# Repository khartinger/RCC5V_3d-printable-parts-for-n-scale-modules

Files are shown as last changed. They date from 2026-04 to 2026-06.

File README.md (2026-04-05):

<table><tr><td></td><td>
Last modified: 2026-04-02 <br>   
<h1>3D Printable Parts for N Scale Modules</h1>
<a href="LIESMICH.md">==> Deutsche Version</a>&nbsp; &nbsp; &nbsp; 
</td></tr></table>   

<a href="LIESMICH.md"><b> Sorry! This page is currently only available in German.</b></a>   

[To the top of the page](#up)

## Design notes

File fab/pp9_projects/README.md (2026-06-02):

<table><tr><td></td><td>
Last modified: 2026-05-27 <br>   
<h1>RCC5V: Little 3D Projects</h1><h3>3D Printable Parts for N Scale Modules</h3>
<a href="LIESMICH.md">==> Deutsche Version</a>&nbsp; &nbsp; &nbsp; 
</td></tr></table>   

<a href="LIESMICH.md"><b> Sorry! This page is currently only available in German.</b></a>   

[To the top of the page](#up)

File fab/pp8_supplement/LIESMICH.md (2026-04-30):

<table><tr><td></td><td>
Letzte &Auml;nderung: 30.4.2026 <br>   
<h1>RCC5V Ergänzungsteile</h1><h3>3D-Druck-Teile für N-Spur-Module</h3>
<a href="#TableOfContents">==> Inhaltsverzeichnis</a>&nbsp; &nbsp; &nbsp;  &nbsp; 
<a href="README.md">==> English version</a>
</td></tr></table>   

# 1. Worum geht es?
Dieses Verzeichnis enthält **Ergänzungsteile**, mit deren Hilfe der Bahnkörper begradigt wird. Das Bild zeigt Straßenteile für einen Bahnübergang.   
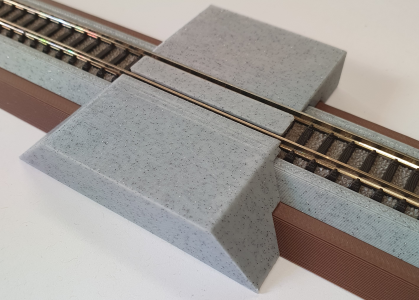
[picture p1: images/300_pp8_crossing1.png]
Bahnuebergang
   

Die Höhe der Teile orientiert sich an folgender Ebenen-Einteilung:   
* E0 . . . . . Oberkante der Basisplatte (= 6 cm &uuml;ber einer Tischplatte). Auf dieser Ebene werden der Bahndamm und, darauf aufbauend, das Schotterbett aufgesetzt.   
* E5 . . . . . Oberkante des Bahndamms. Auf dieser Ebene setzt das Schotterbett auf.   
* E8 . . . . . Auf dieser Ebene liegt das Modellgleis. Hier werden auch Modell-Bahnsteige und Bahnh&ouml;fe platziert. In der Realit&auml;t gibt es diese Ebene eigentlich nicht, da sie mitten in der H&ouml;he des Schotterbettes liegt.   
* E10 . . . . . Oberkante des Schotterbettes bzw. Unterkante des Gleises.   
* E12 . . . . . Oberkante des Gleises. Stra&szlig;en f&uuml;r Bahn&uuml;bersetzungen sollten dieses Niveau haben, wobei Bahn&uuml;bergang-Baus&auml;tze oft eine Art "Rampe" bzw. Auffahrt haben, weil die Baus&auml;tze &uuml;blicherweise auf Ebene E8 platziert werden.   

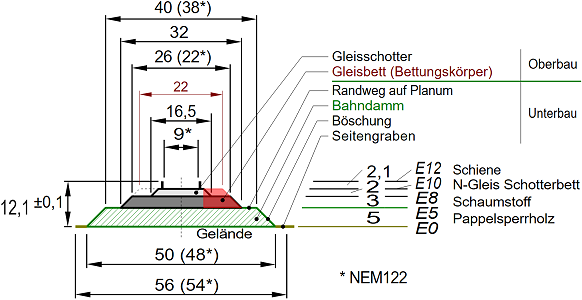
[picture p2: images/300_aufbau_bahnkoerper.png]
Aufbau Bahnk&ouml;rper
   

## Inhaltsverzeichnis
1. [Worum geht es?](#x10)   
2. [Bahnübergang](#x20)   

# 2. Bahnübergang (E12)
Für die Straße bei Bahnübergängen gibt es die Breiten 44 mm und 50 mm mit senkrechter Seitenwand bzw. 68 mm und 74 mm mit schräger Seitenwand (45°). (Siehe Bild oben)  

**Freecad-Dateien**:   
[./fcstd/suppl_straight_E12_44mm_260430.FCStd](https://github.com/khartinger/RCC5V_3d-printable-parts-for-n-scale-modules/tree/main/fab/pp8_supplement/fcstd/suppl_straight_E12_44mm_260430.FCStd)   
[./fcstd/suppl_straight_E12_50mm_260430.FCStd](https://github.com/khartinger/RCC5V_3d-printable-parts-for-n-scale-modules/tree/main/fab/pp8_supplement/fcstd/suppl_straight_E12_50mm_260430.FCStd)   
[./fcstd/suppl_straight_E12_68mm_crossing_260430.FCStd](https://github.com/khartinger/RCC5V_3d-printable-parts-for-n-scale-modules/tree/main/fab/pp8_supplement/fcstd/suppl_straight_E12_68mm_crossing_260430.FCStd)   
[./fcstd/suppl_straight_E12_74mm_crossing_260430.FCStd](https://github.com/khartinger/RCC5V_3d-printable-parts-for-n-scale-modules/tree/main/fab/pp8_supplement/fcstd/suppl_straight_E12_74mm_crossing_260430.FCStd)   

**Slicer-Dateien**:   
[./3mf/suppl_straight_E12_44mm_260430.3mf](https://github.com/khartinger/RCC5V_3d-printable-parts-for-n-scale-modules/tree/main/fab/pp8_supplement/3mf/suppl_straight_E12_44mm_260430.3mf)   
[./3mf/suppl_straight_E12_50mm_260430.3mf](https://github.com/khartinger/RCC5V_3d-printable-parts-for-n-scale-modules/tree/main/fab/pp8_supplement/3mf/suppl_straight_E12_50mm_260430.3mf)   
[./3mf/suppl_straight_E12_68mm_crossing_260430.3mf](https://github.com/khartinger/RCC5V_3d-printable-parts-for-n-scale-modules/tree/main/fab/pp8_supplement/3mf/suppl_straight_E12_68mm_crossing_260430.3mf)   
[./3mf/suppl_straight_E12_74mm_crossing_260430.3mf](https://github.com/khartinger/RCC5V_3d-printable-parts-for-n-scale-modules/tree/main/fab/pp8_supplement/3mf/suppl_straight_E12_74mm_crossing_260430.3mf)   

Zwischen die Gleise wird ein Übergangsbelag gelegt:   
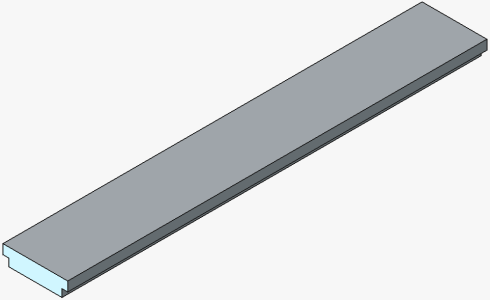
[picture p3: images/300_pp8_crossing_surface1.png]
Bahnuebergang_Uebergangsbelag
   

**Freecad-Datei(en)**:   
[./fcstd/suppl_straight_44mm_crossing_surface_260430.FCStd](https://github.com/khartinger/RCC5V_3d-printable-parts-for-n-scale-modules/tree/main/fab/pp8_supplement/fcstd/suppl_straight_44mm_crossing_surface_260430.FCStd)   
**Slicer-Datei(en)**:   
[./3mf/suppl_straight_44mm_crossing_surface_260430.3mf](https://github.com/khartinger/RCC5V_3d-printable-parts-for-n-scale-modules/tree/main/fab/pp8_supplement/3mf/suppl_straight_44mm_crossing_surface_260430.3mf)   

# 3. Gelände-Begradigung für Gebäude (E8)

# 4. Gelände-Begradigung bei mehreren Gleisen (E10)

[Zum Seitenanfang](#up)

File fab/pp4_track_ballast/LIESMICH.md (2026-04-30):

<table><tr><td></td><td>
Letzte &Auml;nderung: 17.4.2026 <br>   
<h1>Schotterbett (Track Ballast)</h1><h3>3D-Druck-Teile für N-Spur-Module</h3>
<a href="#TableOfContents">==> Inhaltsverzeichnis</a>&nbsp; &nbsp; &nbsp;  &nbsp; 
<a href="README.md">==> English version</a>
</td></tr></table>   

# 1. Worum geht es?
Dieses Verzeichnis enthält **Schotterbett-Dateien** für N-Piccolo-Gleise mit Schotterbett (Fa. Fleischmann) im N‑Spur‑Maßstab (1:160). In diese 3D-Drucke werden die Fleischmann-Gleise eingelegt, damit ein breiteres Schotterbett entsteht.   

_Beispiel_: Schotterbett für gerades Gleis 9103   
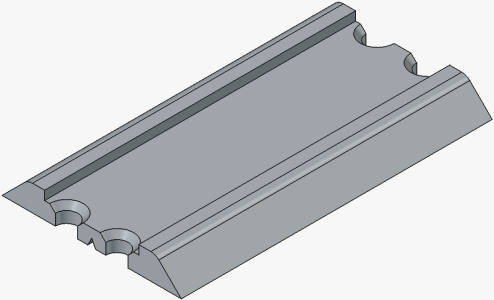
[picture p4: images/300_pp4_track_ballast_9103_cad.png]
Schotterbett Gerade 9103
   

Für alle Modelle gilt:   
* An den Verbindungskanten befinden sich zwei halbe Bohrungen. So können an jeder Stoßstelle Kabel für die Gleisstromversorgung durchgeführt werden. Da sich die Bohrungen unter dem Gleisbett befinden, sind sie von außen nicht sichtbar.   
* In der Mitte der Unterseite der Modelle ist eine Nut. Der Bahndamm hat die dazu passende Erhebung. Damit kann die Lage von 3D-Schotterbett und Bahndamm leicht angepasst werden.   
* Die Längsoberkanten sind abgerundet.   

## Inhaltsverzeichnis
1. [Worum geht es?](#x10)   
2. [Schotterbett für gerade Gleise](#x20)   
3. [Schotterbett für gebogene Gleise](#x30)   
4. [Verkürztes Schotterbett](#x40)   
5. [Schotterbett für Weichen](#x50)   

# 2. Schotterbett für gerade Gleise
Für gerade Gleise gibt es folgende Schotterbetten:   
* 9100 (222 mm)   
* 9101 (111 mm)   
* 9102 (57,5 mm)   
* 9103 (55,5 mm)   
* 9104 (27,75 mm)   
* 9110 (Ausgleichsgleis, 83 mm bis 111 mm)   
* 9116 (Prellbock, 57,5 mm)   

Weitere Besonderheiten sind:   
* `Gerade_Schotter_Abschluss_260327` ... Abschlussstück bei Gleisenden (Prellbock)   
* `Gerade_Schotter_Iso_0.5mm_260327` ... Gerades Gleisstück mit 0,5 mm Länge, wenn Verlängerungen durch Gleisisolierschuhe ausgeglichen werden sollen.   
* `Gerade_Schotter_9101_adWeiche_260327.FCStd` ... Gerades Gleis 9101, bei dem ein Teil des Randschotters entfernt ist. Damit passt es zu Weichen.   
* `Gerade_Schotter_9104_adWeiche_260327.FCStd` ... Wie `Gerade_Schotter_9101_adWeiche_260327.FCStd`, aber für Gleis 9104.   

# 3. Schotterbett für gebogene Gleise
Für gebogene Gleise gibt es folgende Schotterbetten:   
* `Bogen_Schotter_R2_7.5_9128_260327.FCStd` ... Radius R2 (225,6 mm), Winkel 7,5°   
* `Bogen_Schotter_R2_15_9127_260327.FCStd` ... Radius R2 (225,6 mm), Winkel 15°   
* `Bogen_Schotter_R2_45_9125_260327.FCStd` ... Radius R2 (225,6 mm), Winkel 55°   
* `Bogen_Schotter_R3_15_9131_260327.FCStd` ... Radius R3 (396,4 mm), Winkel 15°   
* `Bogen_Schotter_R4_15_9136_260327.FCStd` ... Radius R4 (430 mm), Winkel 15°   

Weitere Besonderheiten sind:   
* `Bogen_Schotter_R3_9.978_9131_260327.FCStd` ... Radius R3 (396,4 mm), Winkel 9,978°   

# 4. Verkürztes Schotterbett
Gleise am Rand des Moduls reichen bis zur Modulkante. Das 3D-Schotterbett endet bereits einen Zentimeter vorher, da der Modul-Seitenteil den Aufbau des Bahnkörpers enthält.   
Weiters gibt es an der Kante zum Seitenteil keine halben Bohrungen.   

Die verkürzten Schotterbetten enthalten im Namen die Bezeichung "-10mm".   
_Beispiele_:   
`Gerade_Schotter_9101_-10mm_260403.FCStd`   
`Gerade_Schotter_9102_-10mm_260403.FCStd`   
`Gerade_Schotter_9103_-10mm_260403.FCStd`   
`Gerade_Schotter_9104_-10mm_260403.FCStd`   

# 5. Schotterbett für Weichen

[Zum Seitenanfang](#up)

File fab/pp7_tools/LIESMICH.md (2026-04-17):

<table><tr><td></td><td>
Letzte &Auml;nderung: 15.4.2026 <br>   
<h1>Werkzeuge und Hilfsmittel</h1><h3>3D-Druck-Teile für N-Spur-Module</h3>
<a href="#TableOfContents">==> Inhaltsverzeichnis</a>&nbsp; &nbsp; &nbsp;  &nbsp; 
<a href="README.md">==> English version</a>
</td></tr></table>   

# 1. Worum geht es?
Dieses Verzeichnis enthält **Werkzeuge** und **Hilfsmittel** für den Bau von Modulrahmen, Gleisunterbau und Zubehörteilen im N‑Spur‑Maßstab (1:160).   
Weitere Hilfsmittel finden sich auch unter [https://github.com/khartinger/RCC5V/blob/main/fab/3d/LIESMICH.md](https://github.com/khartinger/RCC5V/blob/main/fab/3d/LIESMICH.md).   

## Inhaltsverzeichnis
1. [Worum geht es?](#x10)   
2. [Halterung zur Montage eines Unterflur-Weichenantriebs](#x20)   
3. [Schablonen für das Loch bei Unterflurweichen](#x30)   
4. [Gleis-Schnittlehre](#x40)   

# 2. Halterung zur Montage eines Unterflur-Weichenantriebs

Unterflur-Weichenantriebe können mit der Zeit defekt werden und müssen ersetzt werden.   
Da die Weichenantriebs-Öffnungen in der Grundplatte klein sind, ist der Ein- und Ausbau oft schwierig.   

Zum Einbau hilft der folgende **Weichenantriebswechsler**:   

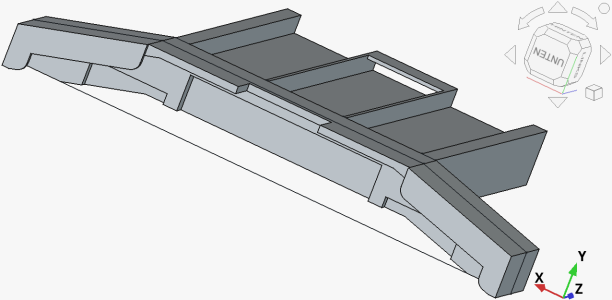
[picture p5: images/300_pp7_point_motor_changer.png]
Weichenantriebswechsler


Der Weichenantrieb wird vorne in die Halterung gesteckt.  
Danach kann er von unten einfach in die Weiche eingesetzt werden.   

**Freecad-Datei**: 
[./fcstd/Weichenantriebswechsler_260226.FCStd](https://github.com/khartinger/RCC5V_3d-printable-parts-for-n-scale-modules/tree/main/fab/pp7_tools/fcstd/Weichenantriebswechsler_260226.FCStd)   
**Slicer-Datei**: 
[./3mf/Weichenantriebswechsler_260226.3mf](https://github.com/khartinger/RCC5V_3d-printable-parts-for-n-scale-modules/tree/main/fab/pp7_tools/3mf/Weichenantriebswechsler_260226.3mf)   

[Zum Seitenanfang](#up)   

# 3. Schablonen für das Loch bei Unterflurweichen
Für die Montage von Unterflur-Weichen gibt es je nach Weichenart unterschiedliche Öffnungen (Löcher). Damit man sie nicht jedes Mal anzeichnen muss, ist eine Schablone hilfreich.   

### Zweiweg-Weichen
Das Bild zeigt die sinnvoll kleinste Ausnehmung für einen Zweiweg-Weichenantrieb.   
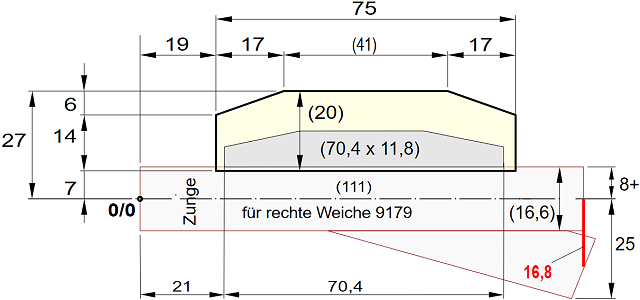
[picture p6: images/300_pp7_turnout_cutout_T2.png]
Maße_Loch_Zweiwegweiche
   

Die Eckpunkte der Öffnung sind (19/7), (94/7), (94/21), (77/27), (36/27) und (19/21).   

Schablone:   
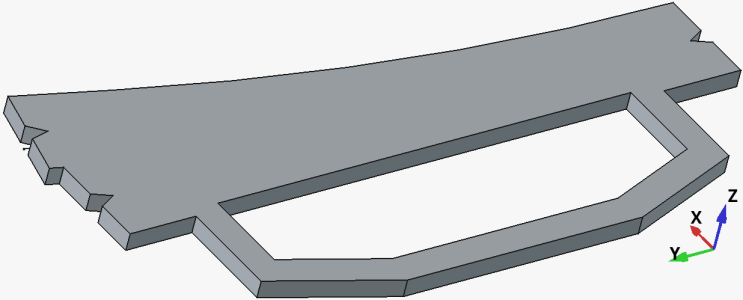
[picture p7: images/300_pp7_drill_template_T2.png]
Schablone_Loch_Zweiwegweiche
   

**Anmerkung**: Falls Platz vorhanden ist, darf die Ausnehmung auch größer sein...   

**Freecad-Datei**: 
[./fcstd/drill_template_T2_260413.FCStd](https://github.com/khartinger/RCC5V_3d-printable-parts-for-n-scale-modules/tree/main/fab/pp7_tools/fcstd/drill_template_T2_260413.FCStd)   
**Slicer-Datei**: 
[./3mf/drill_template_T2_260413.3mf](https://github.com/khartinger/RCC5V_3d-printable-parts-for-n-scale-modules/tree/main/fab/pp7_tools/3mf/drill_template_T2_260413.3mf)   

### Dreiwegweichen
Das Bild zeigt die sinnvoll kleinste Ausnehmungen für Dreiweg-Weichenantriebe.   
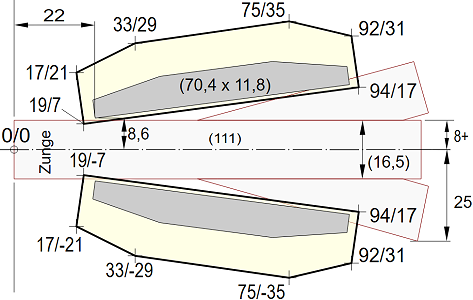
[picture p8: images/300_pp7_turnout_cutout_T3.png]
Maße_Loch_Dreiwegweiche
   

Die Eckpunkte der Öffnungen sind (19/7), (94/17), (92/31), (75/35), (33/29) und (17/21).   

Schablone:   
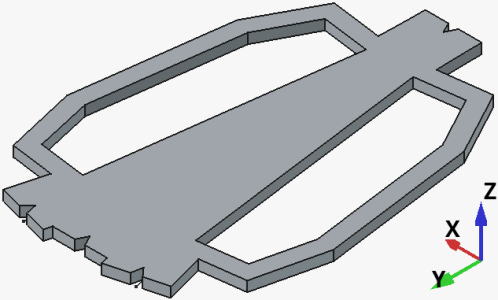
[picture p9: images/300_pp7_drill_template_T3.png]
Schablone_Loch_Dreiwegweiche
   

**Anmerkung**: Falls Platz vorhanden ist, dürfen die Ausnehmungen auch größer sein...   

**Freecad-Datei**: 
[./fcstd/drill_template_T3_260413.FCStd](https://github.com/khartinger/RCC5V_3d-printable-parts-for-n-scale-modules/tree/main/fab/pp7_tools/fcstd/drill_template_T3_260413.FCStd)   
**Slicer-Datei**: 
[./3mf/drill_template_T3_260413.3mf](https://github.com/khartinger/RCC5V_3d-printable-parts-for-n-scale-modules/tree/main/fab/pp7_tools/3mf/drill_template_T3_260413.3mf)   

# 4. Gleis-Schnittlehre

[Zum Seitenanfang](#up)

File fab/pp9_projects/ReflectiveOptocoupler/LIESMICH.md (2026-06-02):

<table><tr><td></td><td>
Letzte &Auml;nderung: 27.5.2026 <br>   
<h1>RCC5V: Reflexkoppler zur Zugerkennung</h1><h3>3D-Druck-Teile für N-Spur-Module</h3>
<a href="#TableOfContents">==> Inhaltsverzeichnis</a>&nbsp; &nbsp; &nbsp;  &nbsp; 
<a href="README.md">==> English version</a>
</td></tr></table>   

# 1. Worum geht es?
Dieses Verzeichnis enthält die Bauanleitung für ein 55,5 mm langes Fleischmann-Schottergleis mit eingebautem Sensorboard HW-870. Das Sensorboard enthält die Reflexlichtschranke TCRT5000.   
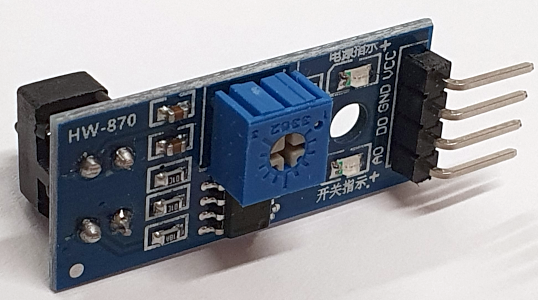
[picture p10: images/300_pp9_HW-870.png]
Sensorboard HW-870
   

## Inhaltsverzeichnis
1. [Worum geht es?](#x10)   
2. [Verwendete Bauteile](#x20)   
3. [Grenzen des Reflexkoppler-Einsatzes](#x30)   
4. [Bau der Reflex-Lichtschranke](#x40)    

# 2. Verwendete Bauteile   
* Fleischmann-Schottergleis, gerade, 55,5 mm lang   
* Sensorboard HW-870   
* FreeCAD Datei `Gerade_Schotter_9103_Opto_260526.FCStd`   
* FreeCAD Datei `Gerade_Damm_9103_Opto_260526.FCStd`   
* FreeCAD Datei `Opto_Beilage_2.2mm_260531.FCStd`   
* Schraube M 2,6 x 10 mm Kreuzschlitz, Halbrundkopf, selbstbohrend   

Weiters sinnvoll:
* Dünnes Doppelklebeband   
* Glasfaserkabel 2,5 mm zum Abdecken der Bohrungen im Gleisschotter   

Bauteile:   
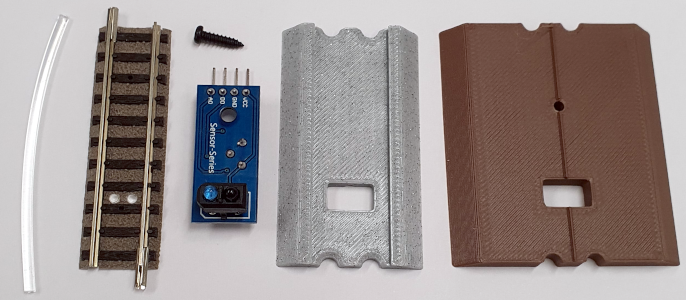
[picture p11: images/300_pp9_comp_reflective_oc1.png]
Bauteile Reflexkoppler
   

Beilage:   
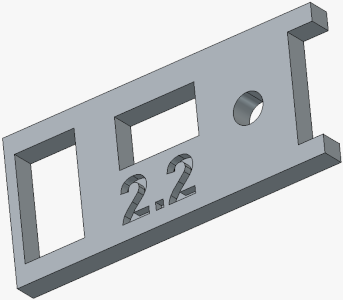
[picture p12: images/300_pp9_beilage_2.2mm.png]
Beilage
   

# 3. Grenzen des Reflexkoppler-Einsatzes
Bei der "Serienfertigung" ergaben sich einige Probleme.   

## 1. Ausrichtung der LEDs am Sensor-Board
Die Reflexlichtschranke TCRT5000 ist nicht direkt auf das Board montiert sondern ca. 10,16 mm über dem Print (Abstand Oberkanten). Damit ergeben sich Lage-Ungenauigkeiten und der Abstand für die Bohrungen im Gleis schwankt zwischen ca. 3,8 mm und 3,1 mm.   

## 2. Umgebungshelligkeit
Befinden sich direkt über dem Koppler starke Lampen oder Sonnenlicht, so schaltet der Empfänger auch ohne Opjekt durch. In diesem Fall kann man die Empfindlichkeit mit dem Poti auf dem Sensorboard reduzieren. Dreht man die Empfindlichkeit zurück so kann es sein, dass dann auch kein Waggon mehr erkannt wird.   

# 4. Bau der Reflex-Lichtschranke
__Montage Sensorboard__   
1. Drucken der 3D-Teile `Gerade_Schotter_9103` und `Damm_Schotter_9103`   
2. Zusammenfügen der Teile mit einem dünnen Doppelklebeband   
3. Drucken des Abstandshalters `Opto_Beilage_2.2mm_260531`   
4. Anlegen des Abstandshalters an das Sensorboard und Einstecken des Boards in die Öffnung des Gleisbettes   
5. Anschrauben des Sensorboards an das Gleisbett   

__Fleischmann-Gleis__
1. `Optobohrlehre_9103_3.4mm_260531` fluchtend auf das Gleis legen.   
2. Auf die beiden Bohrungen von oben draufschauen und kontrollieren, ob die Bohrungen wirklich genau zwischen zwei Schwellen liegen. Dann Optobohrlehre mit Klebeband fixieren.   
3. 2x 2,6 mm Bohrungen in das Gleisbett bohren.   
4. Optobohrlehre entfernen, Glasfaserkabel 2,5 mm durch die Bohrungen im Gleisbett stecken und ablängen.   

Optobohrlehre:   
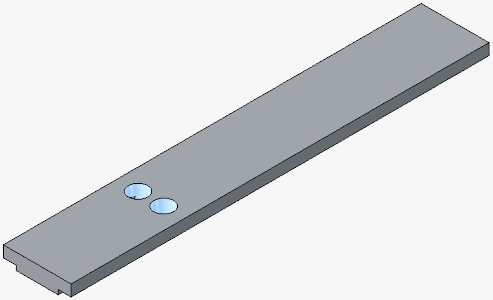
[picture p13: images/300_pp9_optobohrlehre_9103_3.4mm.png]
   

[Zum Seitenanfang](#up)

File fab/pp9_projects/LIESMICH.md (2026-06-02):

<table><tr><td></td><td>
Letzte &Auml;nderung: 27.5.2026 <br>   
<h1>RCC5V: Kleine 3D-Projekte</h1><h3>3D-Druck-Teile für N-Spur-Module</h3>
<a href="#TableOfContents">==> Inhaltsverzeichnis</a>&nbsp; &nbsp; &nbsp;  &nbsp; 
<a href="README.md">==> English version</a>
</td></tr></table>   

# 1. Worum geht es?
Dieses Verzeichnis enthält kleine **3D-Projekte** für N-Spur-Module Die Projekte sind in Unterverzeichnissen abgelegt und enthalten alle notwendigen Informationen.   

## Inhaltsverzeichnis
1. [Worum geht es?](#x10)   
2. [Reflexpoppler zur Gleisbesetzt-Erkennung](#x10)   

[Zum Seitenanfang](#up)

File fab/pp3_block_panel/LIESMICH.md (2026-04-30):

<table><tr><td></td><td>
Letzte &Auml;nderung: 6.4.2026 <br>   
<h1> Blockpanel</h1><h3>3D-Druck-Teile für N-Spur-Module</h3>
<a href="#TableOfContents">==> Inhaltsverzeichnis</a>&nbsp; &nbsp; &nbsp;  &nbsp; 
<a href="README.md">==> English version</a>
</td></tr></table>   

# 1. Worum geht es?
Blockpanels sind die **Frontplatten für Steuerblöcke** aus dem Repository [`khartinger/RCC5V`](https://github.com/khartinger/RCC5V/blob/main/LIESMICH.md).   
Für jeden Steuerblock gibt es das passende Frontpanel.   

_Beispiel_: Blockpanel für eine linke Zweiwegweiche:   
Blockpanel_Zweiwegweiche   

## Inhaltsverzeichnis
1. [Worum geht es?](#x10)   
2. [Gemeinsame Eigenschaften von Blockpanels](#x20)   
3. [Panel für Zweiwegweichen](#x30)   
4. [Panel für Dreiwegweichen](#x40)   
5. [Panel für Entkuppler](#x50)   
6. [Panel für ein abschaltbares Gleis](#x60)   
7. [Weitere Blockpanels](#x70)   

# 2. Gemeinsame Eigenschaften von Blockpanels
Alle Blockpanels:  
- haben **Löcher für Taster und LEDs**   
- zeigen die **Funktion des Steuerblocks** symbolisch   
- haben ein **Beschriftungsfeld**   
- haben **die gleichen Abmessungen**   

**Beschriftungsfeld:** 40 × 7 mm²  
**Außenmaße:** 46 × 54 mm²  
**Maße des 10 mm dicken Blocks:** 42 × 42 mm²

# 3. Panel für Zweiwegweichen
Zweiwegweichen gibt es als **links oder rechts abzweigende Weichen**.   
Sie können in Modulen nach **links (West)** oder **rechts (Ost)** geöffnet sein.   
Damit gibt es **vier Varianten**:   

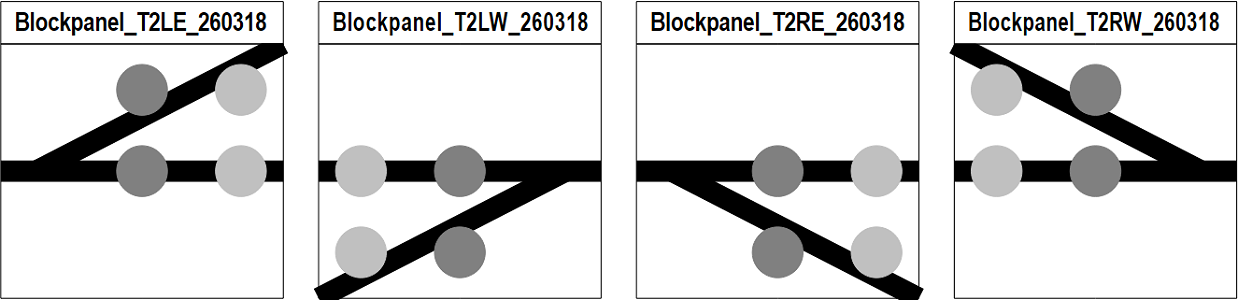
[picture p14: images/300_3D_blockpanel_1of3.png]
Blockpanel_Zweiwegweiche
   

**Dateien:**  
* `Blockpanel_T2LE_260318.FCStd` – linke Zweiwegweiche Richtung Osten   
* `Blockpanel_T2LW_260318.FCStd` – linke Zweiwegweiche Richtung Westen   
* `Blockpanel_T2RE_260318.FCStd` – rechte Zweiwegweiche Richtung Osten   
* `Blockpanel_T2RW_260318.FCStd` – rechte Zweiwegweiche Richtung Westen   

# 4. Panel für Dreiwegweichen
Dreiwegweichen können nach **links (West)** oder **rechts (Ost)** geöffnet sein.   
Es gibt **zwei Varianten**:   

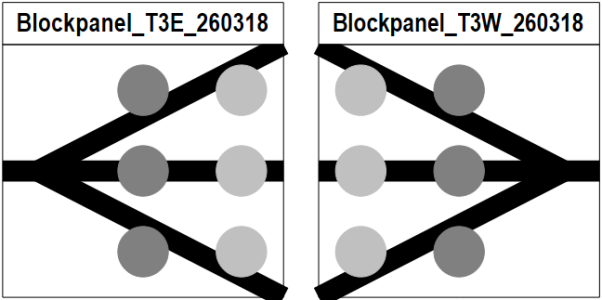
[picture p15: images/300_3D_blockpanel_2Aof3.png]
Blockpanel_Dreiwegweiche
   

**Dateien:**   
* `Blockpanel_T3E_260318.FCStd` – Dreiwegweiche Richtung Osten   
* `Blockpanel_T3W_260318.FCStd` – Dreiwegweiche Richtung Westen   

# 5. Panel für Entkuppler
Das Panel für Entkuppler gibt es mit und ohne 3D-gedrucktem Text:   
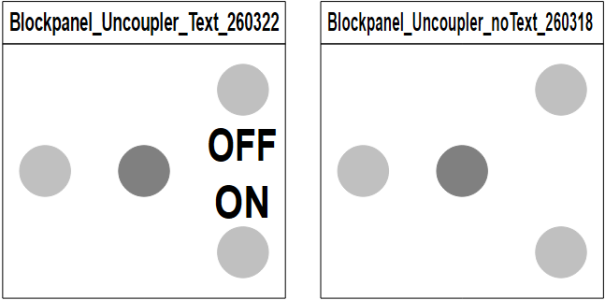
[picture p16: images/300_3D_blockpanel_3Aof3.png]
Blockpanel_Entkuppler
   

**Dateien:**   
* `Blockpanel_Uncoupler_Text_260322.FCStd` ... Entkuppler   
* `Blockpanel_Uncoupler_noText_260318.FCStd` ... Entkuppler (ohne Text)   

# 6. Panel für ein abschaltbares Gleis
Das Panel für ein abschaltbares Gleis gibt es mit und ohne 3D-gedrucktem Text:   
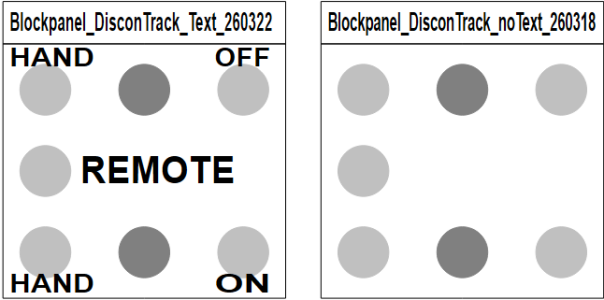
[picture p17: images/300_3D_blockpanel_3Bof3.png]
Blockpanel_Gleis
   

**Dateien:**   
* `Blockpanel_DisconTrack_Text_260322.FCStd` ... Abschaltbares Gleis   
* `Blockpanel_DisconTrack_noText_260318.FCStd` ... Abschaltbares Gleis (ohne Text)   

# 7. Weitere Blockpanels
Wenn ein Rahmen eine Ausnehmung hat, die man nicht mehr benötigt, dann kann man ein leeres Blockpanel hineinstecken.   
Mit dem leeren Blockpanel-Shield kann man die Schrauben zwischen den Frontrahmenteilen abzudecken.   

**Dateien:**   
* `Blockpanel_empty_260403.FCStd` ... Leeres Blockpanel   
* `Blockpanel_empty_shield_260405.FCStd` ... Leeres Blockpanel-Shield ohne PadBlock   
* `Blockpanel_all_east_260318.FCStd` ... Blockpanel mit allen Bohrungen und einem Dreiwegweichensymbol (für Testzwecken)   

[Zum Seitenanfang](#up)

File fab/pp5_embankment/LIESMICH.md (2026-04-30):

<table><tr><td></td><td>
Letzte &Auml;nderung: 17.4.2026 <br>   
<h1>Bahndamm (Embankment)</h1><h3>3D-Druck-Teile für N-Spur-Module</h3>
<a href="#TableOfContents">==> Inhaltsverzeichnis</a>&nbsp; &nbsp; &nbsp;  &nbsp; 
<a href="README.md">==> English version</a>
</td></tr></table>   

# 1. Worum geht es?
Dieses Verzeichnis enthält **Bahndamm-Dateien** für N-Piccolo-Gleise mit Schotterbett (Fa. Fleischmann) und 3D-Schotterbett.   
_Beispiel_: Bahndamm für gerades Gleis 9103   
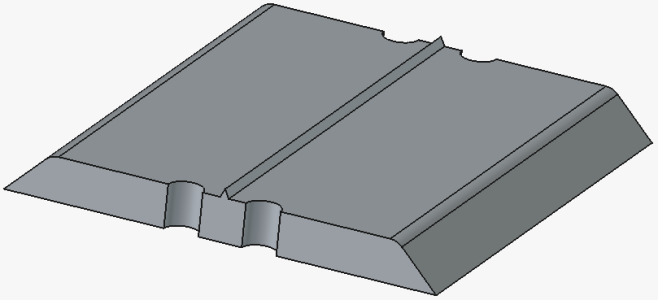
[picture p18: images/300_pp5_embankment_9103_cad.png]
Bahndamm Gerade 9103
   

Für alle Modelle gilt:  
* An den Verbindungskanten befinden sich zwei halbe Bohrungen. So können an jeder Stoßstelle Kabel für die Gleisstromversorgung durchgeführt werden. Da sich die Bohrungen unter dem Gleisbett befinden, sind sie von außen nicht sichtbar.  
* In der Mitte der Unterseite der Modelle ist Erhebung. Damit kann die Lage von 3D-Schotterbett und Bahndamm leicht angepasst werden.  
* Die Längsoberkanten sind abgerundet.  

## Inhaltsverzeichnis
1. [Worum geht es?](#x10)   
2. [Bahndamm für gerade Gleise](#x20)   
3. [Bahndamm für gebogene Gleise](#x30)   
4. [Verkürzter Bahndamm](#x40)   
5. [Bahndamm für Weichen](#x50)   

# 2. Bahndamm für gerade Gleise

# 3. Bahndamm für gebogene Gleise

# 4. Verkürzter Bahndamm

# 5. Bahndamm für Weichen

[Zum Seitenanfang](#up)

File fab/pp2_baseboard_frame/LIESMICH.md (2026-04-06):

<table><tr><td></td><td>
Letzte &Auml;nderung: 6.4.2026 <br>   
<h1>Rahmenteile</h1><h3>3D-Druck-Teile für N-Spur-Module</h3>
<a href="#TableOfContents">==> Inhaltsverzeichnis</a>&nbsp; &nbsp; &nbsp;  &nbsp; 
<a href="README.md">==> English version</a>
</td></tr></table>   

# Worum geht es?
Dieses Verzeichnis enthält Details zu den Rahmenteilen sowie die Freecad-Zeichnungen.   
Das folgende Bild gibt eine Übersicht über die Rahmenteile.   

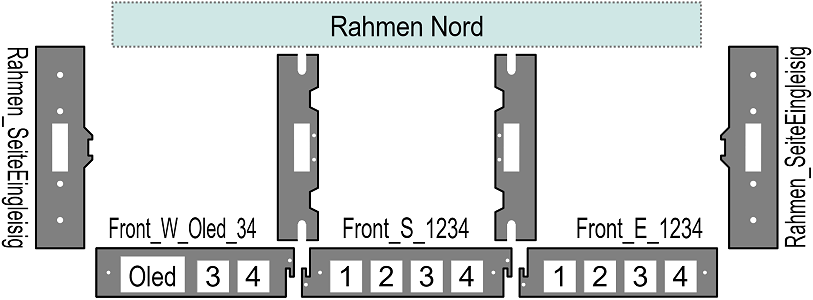
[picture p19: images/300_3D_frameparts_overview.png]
Uebersicht Rahmenteile
   
_Bild 1: Übersicht über die Lage der Rahmenteile_   

Es gibt   
1. [Seitenteile ("West", "Ost")](#x10)   
2. [Frontrahmen (im Süden - "West", "Süd", "Ost")](#x20)   
3. [Rückseitiger Rahmen ("Nord")](#x30)   
4. [Querstreben](#x40)   
5. [Distanzplättchen](#x50)   

# 1. Seitenteile
Seitliche Rahmenteile ("Seitenteile") bestehen aus dem Basisteil und dem Aufsatz für das Gleis (im Bild blau markiert):   
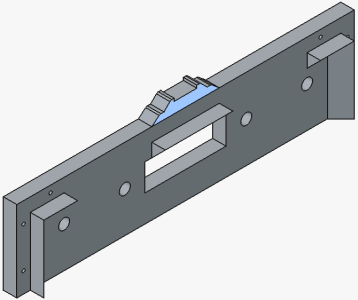
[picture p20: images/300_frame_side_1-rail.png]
Seitlicher Rahmenteil
   
_Bild 2: Seitlicher Rahmenteil mit einem Gleis in der Mitte_   

Die Maße zeigt das folgende Bild:   
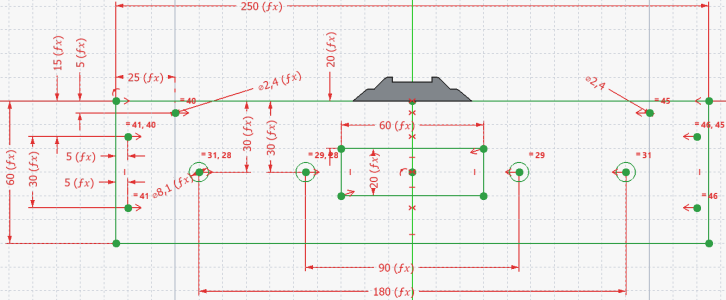
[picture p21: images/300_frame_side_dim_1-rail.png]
Maße seitlicher Rahmenteil
   
_Bild 3: Maße des seitlichen Rahmenteils mit einem Gleis in der Mitte_   

_**Dateinamen**_:   
* `Rahmen_SeiteEingleisig_260312.FCStd` ... Eingleisiger Seitenteil mit Gleis in der Mitte des Rahmenteils   
* `Rahmen_SeiteZweigleisig_260312.FCStd` ... Zweigleisiger Seitenteil mit zwei Gleisen in der Mitte des Rahmenteils   

# 2. Frontrahmen
Die Längsrahmenteile haben kleine Haken (2 mm), damit sie zusammenhalten. Deshalb unterscheidet man   
* Frontrahmen West   
* Frontrahmen Süd (Mitte)   
* Frontrahmen Ost   

_**Zusammenbau**_   
Die Nasen der Frontrahmen werden zusammengehängt und durch die Noppen in den Querstreben sowie durch M3x25 mm Schrauben fixiert.   

_**Dateinamen**_:   
Frontrahmen können Aussparungen für Steuerblöcke und/oder den OLED-Block (Steuerblock) enthalten. Dies steht dann in den Dateinamen:   

`Rahmen_Front_L_1234_240mm_260401.FCStd`   
` Name _ Typ _L_Fenster_Länge_Datum`   
mit   
`L ......` Lage: E = Ost (East), S = Süd, W = West   
`1234 ...` Fenster (1 bis 4 oder OLED)   

__*Beispiel*__   
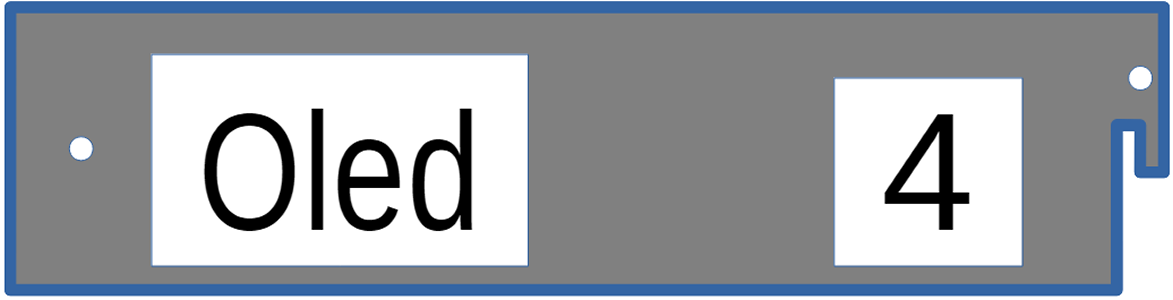
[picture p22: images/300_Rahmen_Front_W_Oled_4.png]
Rahmen_Front_W_Oled_4
   
 Ein Frontrahmen an der Westseite mit Oled-Aussparung und einem Fenster an der 4. Position hat somit den Dateinamen   
`Rahmen_Front_W_Oled_4_240mm_260401.FCStd`    

# 3. Rückseitiger Rahmen ("Nord")
Der rückseitige (nördliche) Rahmen wird oft aus Pappelsperrholz gefertigt, da dieser meist einfach zu fertigen und preiswerter ist.   
Es können aber auch 3D-Frontrahmen ohne Aussparungen verwendet werden.   

# 4. Querstreben
Die Querstreben für den 3D-Rahmen unterscheiden sich von den Holzquerstreben durch die Lage der seitlichen Bohrungen, Noppen bei den Bohrungen und die Lage der seitlichen Durchführung:   

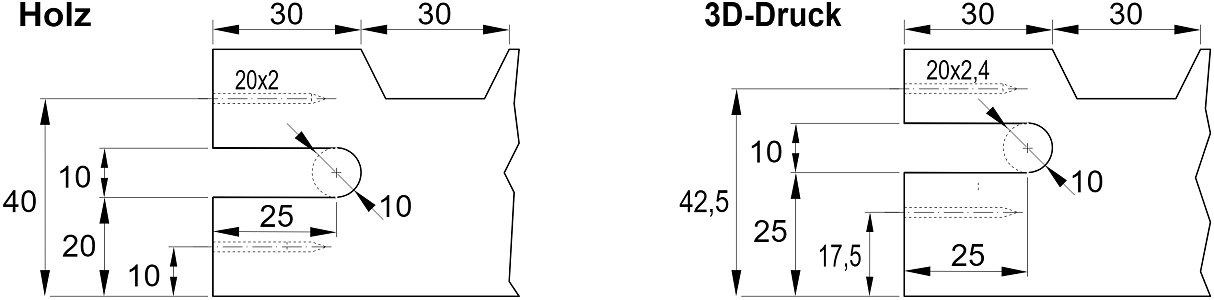
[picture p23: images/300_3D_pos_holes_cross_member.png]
Bohrungen Querstreben
   
_Bild 4: Maße der seitlichen Bohrungen und Durchführungen bei Holz- und 3D-Querstreben_   

Auf den seitlichen Bohrungen befinden sich Noppen, um die Frontteile zu fixieren. Die Größe der Noppen entspricht in etwa dem Kopf von Senkschrauben M3x25 mm.   

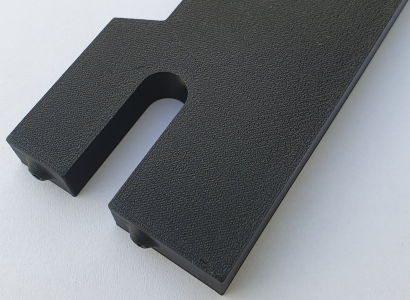
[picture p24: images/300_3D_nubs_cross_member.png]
Noppen Querstreben
   
_Bild 5: Noppen auf den seitlichen Bohrungen bei 3D-Querstreben_   

_**Dateiname**_:   
`Rahmen_Quer_230mm_260313.FCStd`   

# 5. Rahmen-Distanzplättchen
Sollte die Zusammenstellung der Front- (oder Nord-) Rahmen zu kurz sein, so kann durch Einfügen von Rahmen-Distanzplättchen die passende Länge erreicht werden. Die Plättchen werden zB zwischen dem Front_E-Rahmen und dem Seitenteil eingefügt und haben Dicken von 0,8 mm, 1 mm, 2,5 mm oder 2 mm.   
Rahmen-Distanzplättchen   
_Bild 6: Rahmen-Distanzplättchen_   

_**Dateinamen**_:   
`Rahmen_Distanzplatte_0.8mm_260404.FCStd`   
`Rahmen_Distanzplatte_1.0mm_260404.FCStd`   
usw.   
[Zum Seitenanfang](#up)

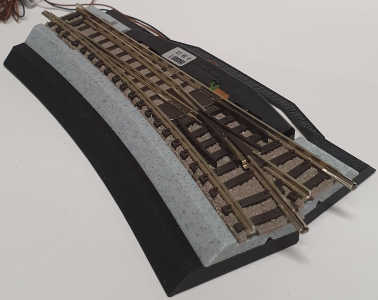
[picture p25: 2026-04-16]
images/300_bahnkoerper1.png

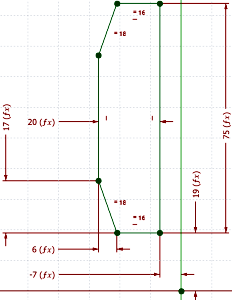
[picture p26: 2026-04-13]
images/300_pp6_point_motor_cover_t2r_hole.png

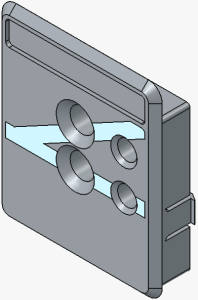
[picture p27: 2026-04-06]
images/300_3D_blockpanel_W2LE.png

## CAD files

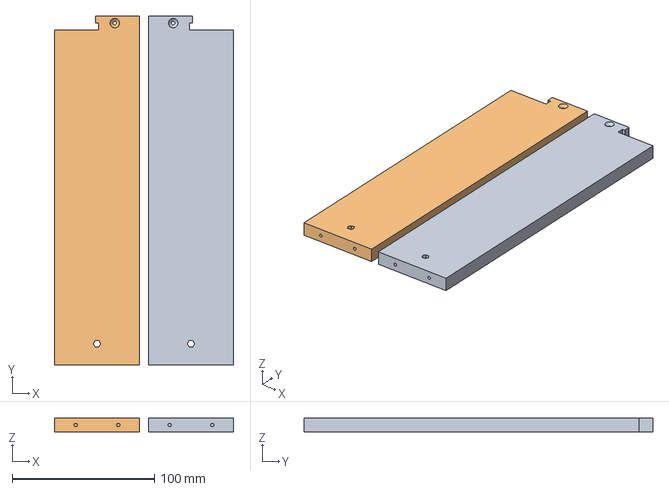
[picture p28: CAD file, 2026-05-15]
fab/pp2_baseboard_frame/3mf/Rahmen_2xBack_EW_240mm_prusa_260515.3mf
126.0 x 245.0 x 10.0 mm
Rahmen_Back_W_240mm_260515 x 2

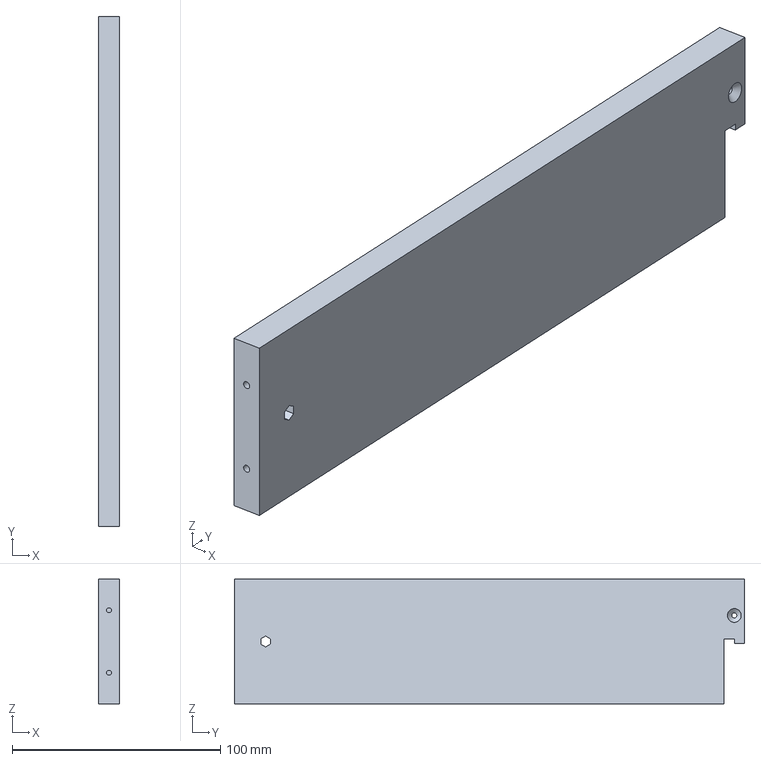
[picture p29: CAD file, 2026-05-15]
fab/pp2_baseboard_frame/fcstd/Rahmen_Back_W_240mm_260515.FCStd
10.0 x 245.0 x 60.0 mm

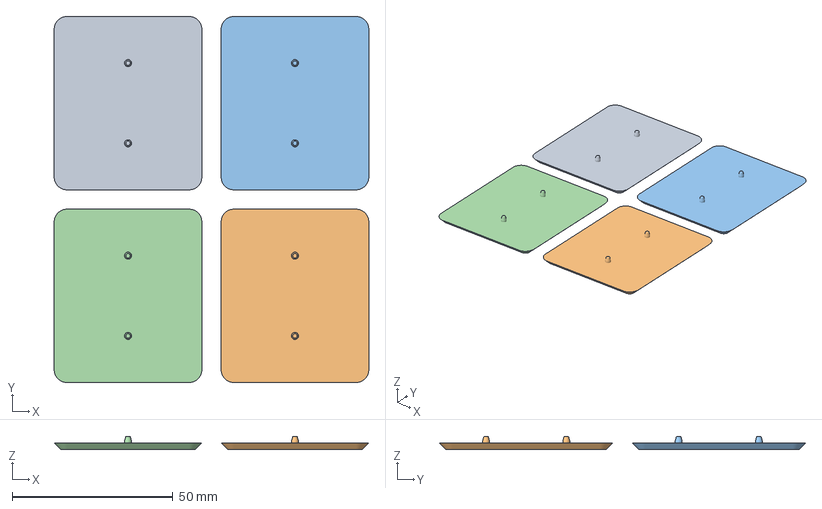
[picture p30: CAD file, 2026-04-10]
fab/pp3_block_panel/3mf/Blockpanel_4x_empty_shield_2.2mm_260405.3mf
98.0 x 114.0 x 4.00 mm
Blockpanel_empty_shield_2.2mm_260405 x 4

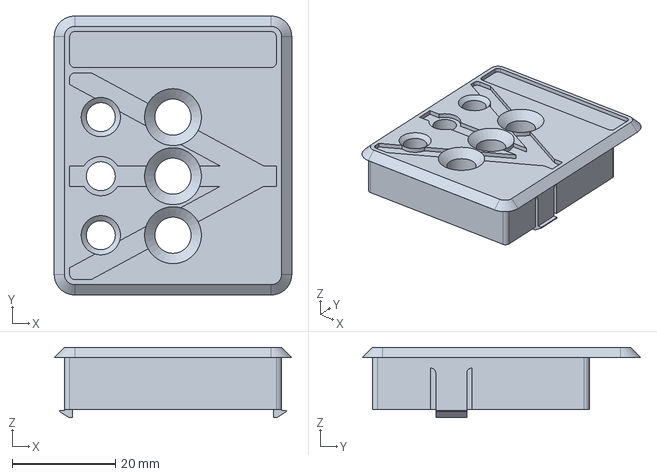
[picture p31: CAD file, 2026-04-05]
fab/pp3_block_panel/fcstd/addon/Blockpanel_T3W_1Koerper_260318.FCStd
46.0 x 54.0 x 13.6 mm

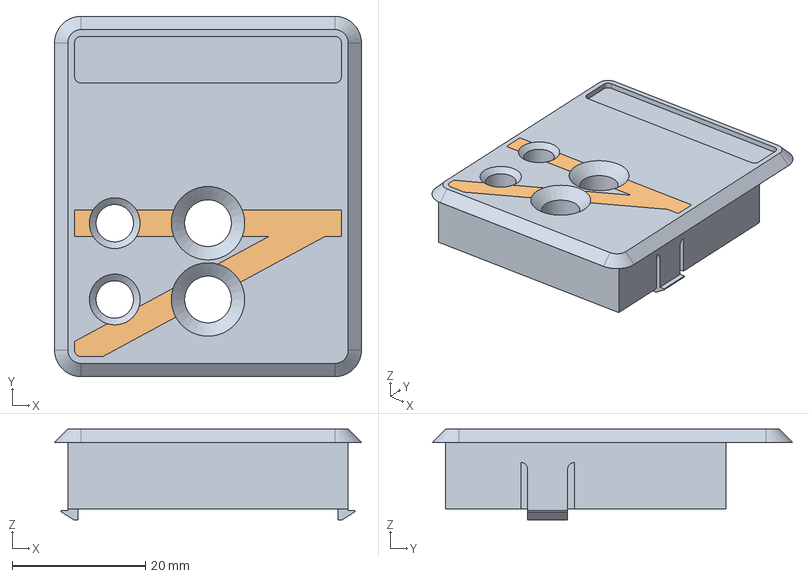
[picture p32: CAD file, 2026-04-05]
fab/pp3_block_panel/fcstd/Blockpanel_T2LW_260318.FCStd
46.0 x 54.0 x 13.6 mm
KörperBlock
KörperSymbol

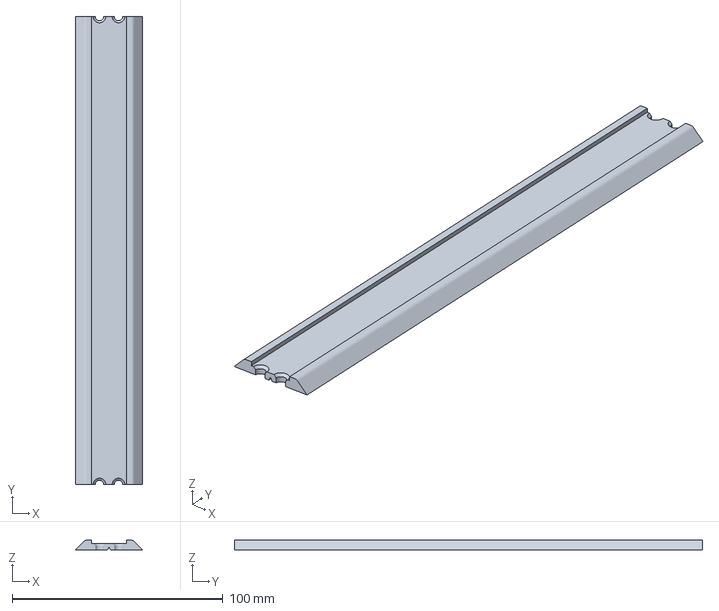
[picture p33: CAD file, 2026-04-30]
fab/pp4_track_ballast/3mf/Gerade_Schotter_9100_260327.3mf
32.0 x 222.0 x 4.60 mm

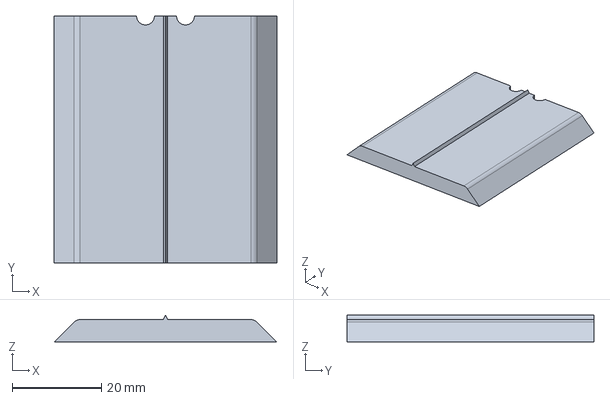
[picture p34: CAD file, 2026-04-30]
fab/pp5_embankment/fcstd/Gerade_Damm_9116_2B_260311.FCStd
50.0 x 55.5 x 6.00 mm

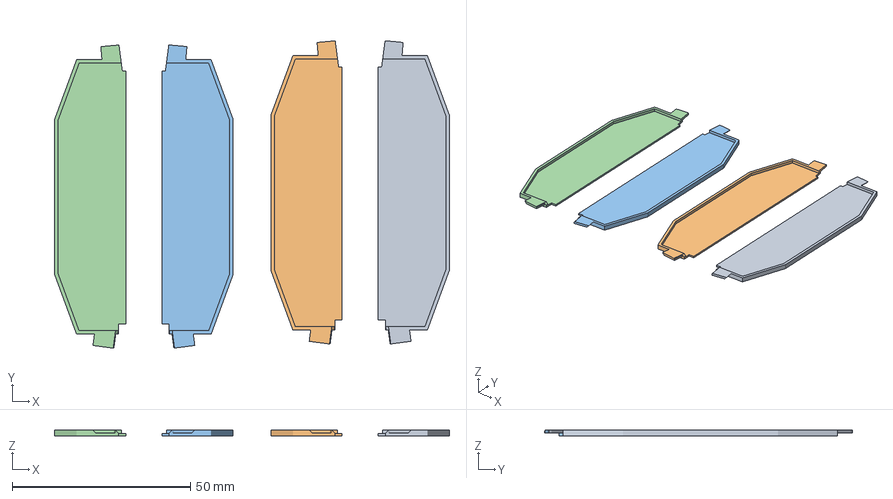
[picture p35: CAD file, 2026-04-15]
fab/pp6_point_motor_cover/3mf/point_motor_cover_t3_E8_2xpair_260413.3mf
110.8 x 86.2 x 1.60 mm
point_motor_cover_t3r_E8_260413 x 4

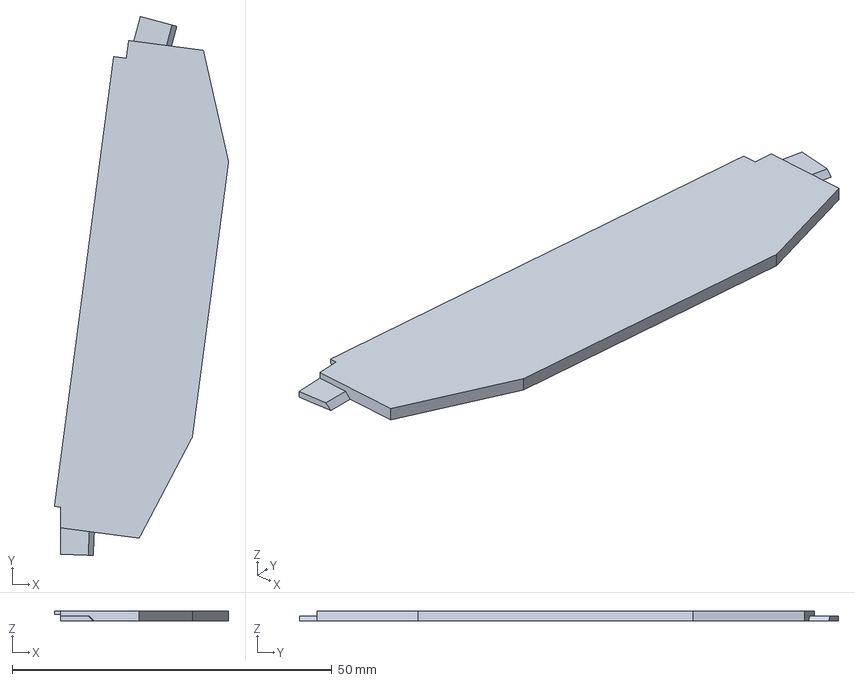
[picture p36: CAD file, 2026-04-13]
fab/pp6_point_motor_cover/fcstd/point_motor_cover_t3r_E8_260413.FCStd
27.3 x 84.3 x 1.60 mm

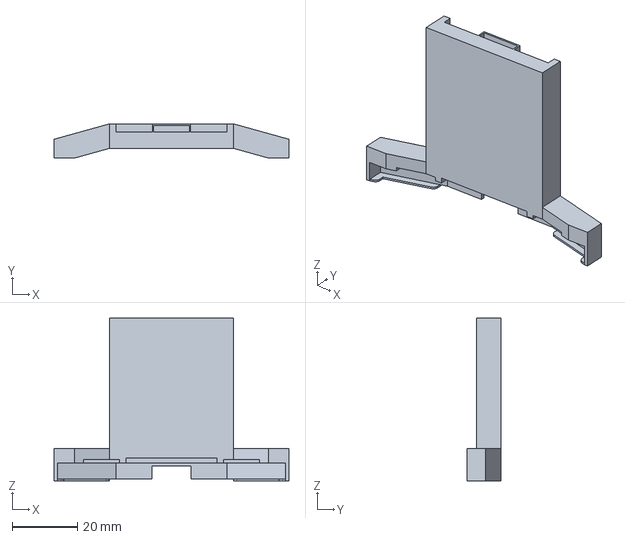
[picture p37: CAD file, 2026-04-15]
fab/pp7_tools/fcstd/Weichenantriebswechsler_260226.FCStd
72.2 x 10.5 x 50.0 mm

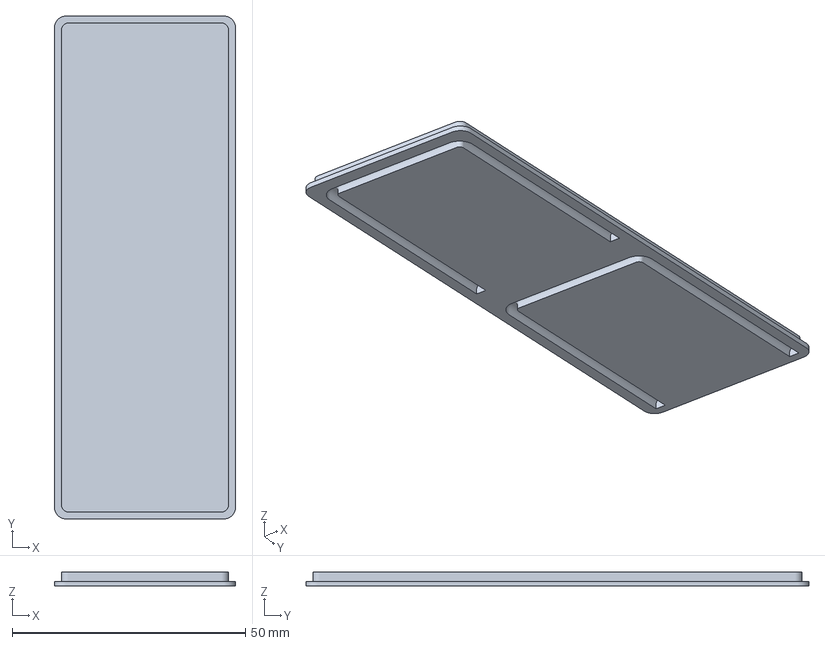
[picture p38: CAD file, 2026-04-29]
fab/pp7_tools/raaco_lid/3mf/Raacodeckel_A9-2_1x_PETG_260427.3mf
38.8 x 107.8 x 3.00 mm

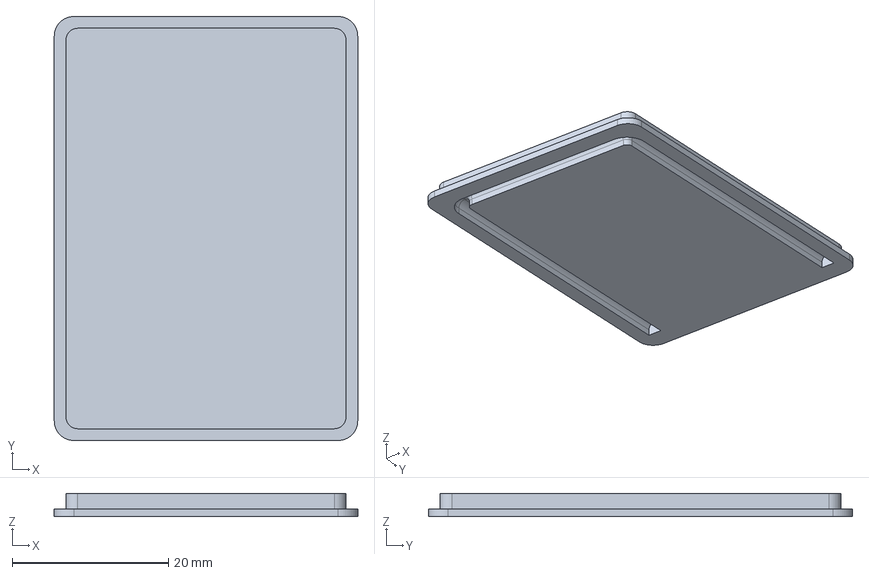
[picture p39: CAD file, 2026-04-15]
fab/pp7_tools/raaco_lid/fcstd/Raacodeckel_A9-1_260415.FCStd
38.8 x 54.2 x 3.00 mm

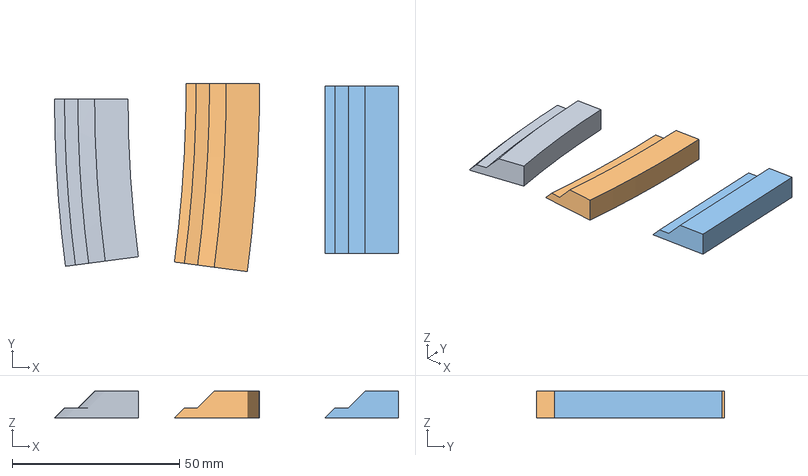
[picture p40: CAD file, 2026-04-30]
fab/pp8_supplement/3mf/suppl_straightcurvedR3_E8_7.5deg_260429.3mf
102.9 x 56.3 x 8.00 mm
suppl_curvedR3in_E8_7.5deg_260429
suppl_curvedR3out_E8_7.5deg_260429
suppl_straight_E8_50mm_260429

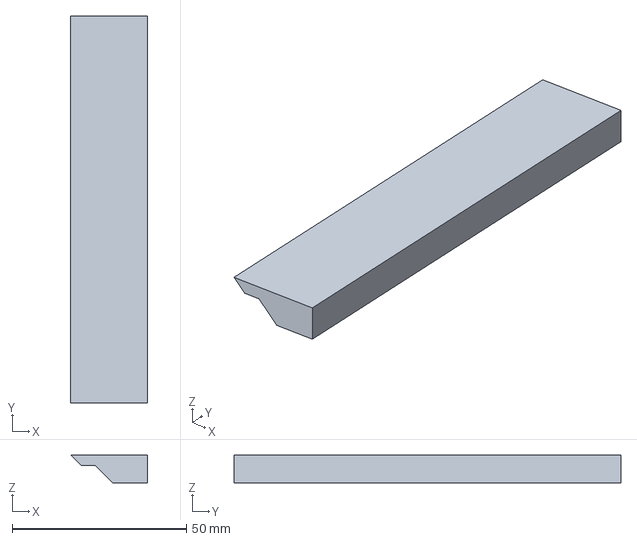
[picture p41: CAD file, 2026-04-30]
fab/pp8_supplement/fcstd/suppl_straight_E8_111mm_260429.FCStd
22.0 x 111.0 x 8.00 mm

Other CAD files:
fab/pp4_track_ballast/fcstd/Gerade_Schotter_9100_260429.FCStd
fab/pp9_projects/ReflectiveOptocoupler/3mf/Optobohrlehre_9103_260531.3mf
fab/pp9_projects/ReflectiveOptocoupler/fcstd/Opto_Beilage_1.8mm_260531.FCStd
fab/pp2_baseboard_frame/3mf/Rahmen_2xFront_S__230mm_260408.3mf
fab/pp2_baseboard_frame/3mf/Rahmen_2xSeiteEingleisig_260312.3mf
fab/pp2_baseboard_frame/3mf/Rahmen_4xDistanzplatte_0.8mm_260404.3mf
fab/pp2_baseboard_frame/3mf/Rahmen_4xDistanzplatte_1.0mm_260404.3mf
fab/pp2_baseboard_frame/3mf/Rahmen_4xDistanzplatte_1.5mm_260404.3mf
fab/pp2_baseboard_frame/3mf/Rahmen_4xDistanzplatte_2.0mm_260404.3mf
fab/pp2_baseboard_frame/3mf/Rahmen_Back_W_240mm_260515.3mf
fab/pp2_baseboard_frame/3mf/Rahmen_Distanzplatte_0.8mm_260404.3mf
fab/pp2_baseboard_frame/3mf/Rahmen_Distanzplatte_1.0mm_260404.3mf
fab/pp2_baseboard_frame/3mf/Rahmen_Distanzplatte_1.5mm_260404.3mf
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

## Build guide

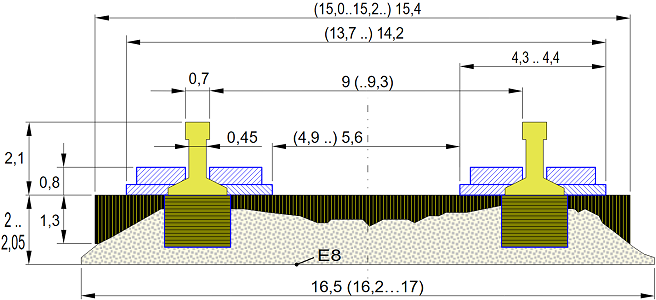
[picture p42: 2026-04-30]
images/300_GleisaufbauFleischmann_260430.png

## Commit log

2026-04-05 Add baseboard_frame FCStd files
    [Rahmen_Distanzplatte_0.8mm_260404.FCStd, Rahmen_Distanzplatte_1.0mm_260404.FCStd, Rahmen_Distanzplatte_1.5mm_260404.FCStd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]
2026-04-05 Add block panel freecad-files
    [Blockpanel_DisconTrack_Text_260322.FCStd, Blockpanel_DisconTrack_noText_260318.FCStd, Blockpanel_T2LE_1Koerper_260318.FCStd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]
2026-04-06 Move FCStd-files to new subfolder fcstd
    [Blockpanel_DisconTrack_Text_260322.FCStd, Blockpanel_DisconTrack_noText_260318.FCStd, Blockpanel_T2LE_1Koerper_260318.FCStd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]
2026-04-10 Add 3mf files
    [6xBlockpanel_prusa_260319.3mf, Block_alles_260314.3mf, Blockpanel_4x_empty_prusa_260404.3mf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]
2026-04-10 Add FCStd files
    [Bogen_Damm_R2_15_9127_260311.FCStd, Bogen_Damm_R2_45_9125_260311.FCStd, Bogen_Damm_R3_15_9131_260311.FCStd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]
2026-04-13 Update LIESMICH.md and FCStd files
    [Weiche3_Damm_260409.FCStd, drill_template_T2_260413.3mf, drill_template_T2_260413.FCStd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]
2026-04-15 Add 3mf and FCStd files
    [Raacodeckel_A8-1_260415.3mf, Raacodeckel_A8-1_260415.FCStd, Raacodeckel_A9-1_260415.FCStd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]
2026-04-15 Update LIESMICH
    [Weichenantriebswechsler_260226-Body.3mf, Weichenantriebswechsler_260226.FCStd]
2026-04-15 Change 3mf-File
    [Weichenantriebswechsler_260226.3mf]
2026-04-17 Add FCStd and 3mf files
    [Bogen_Schotter_R2_7.5_9128_260327.3mf, Bogen_Schotter_R2_7.5_9128_260327.FCStd, Gerade_Schotter_9101_-10mm_260403.3mf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]
2026-04-29 Add Gerade_*9100
    [Gerade_Damm_9100_260429.3mf, Gerade_Damm_9100_260429.FCStd, Gerade_Damm_9101_260311.3mf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]
2026-04-30 Update freecad files
    [Gerade_Damm_9100_260429.3mf, Gerade_Damm_9101_260311.3mf, Gerade_Damm_9103_260311.3mf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]
2026-05-15 Add Freecad baseboard_frame files
    [Rahmen_2xBack_EW_240mm_prusa_260515.3mf, Rahmen_Back_W_240mm_260515.3mf, Rahmen_Back_W_240mm_260515.FCStd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]
2026-06-02 Add pp9_projects
    [Gerade_Damm_9103_Opto_260526.3mf, Gerade_Damm_9103_Opto_260526.FCStd, Gerade_Schotter_9103_Opto_260526.3mf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]
2026-08-31 Update Gleise mit Reed und Opto Aussparung
2026-10-22 add frame_back_*_261021.FCStd
